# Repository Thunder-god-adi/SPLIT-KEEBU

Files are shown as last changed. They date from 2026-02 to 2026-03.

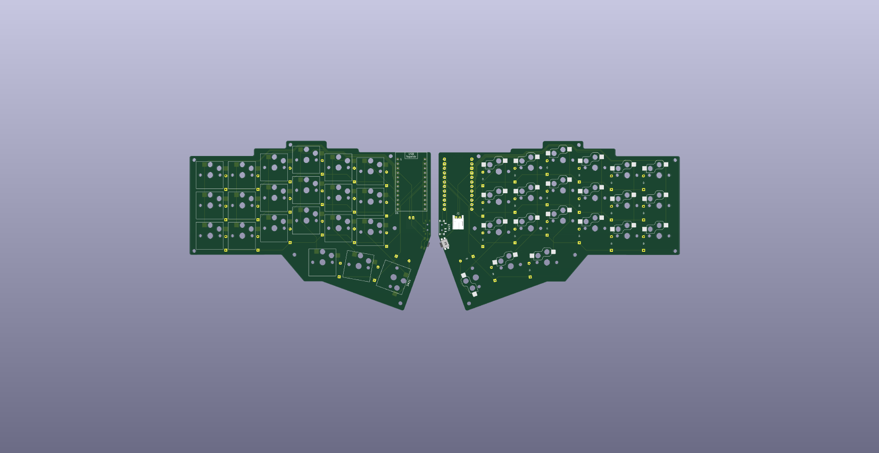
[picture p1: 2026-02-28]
Images/Screenshot 2026-02-26 025907.png

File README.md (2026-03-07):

This my 42 key wireless split keyboard! It follows the corne layout I believe with a 3x6+3 layout. This is my 2nd ever PCB project, so it was very fun! It will use 42 choc switches and hotswap sockets, and is powered by a supermini nrf52840 (nice nano clone).

BOM Request for GRANT:
| Component | Quantity | Price (USD) | Source |
| --- | --- | --- | --- |
|Supermini NRF52840| 2 | $17 | https://robu.in/product/promicro-nrf52840-development-board/
| TTC Low Profile Red Switch | 50 | $19  |https://stackskb.com/store/ttc-low-profile-red-switch-linear/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 |
| PCB | 5 for each side | $32 | JLCPCB |
| Hotswap Sockets | 42 | $7 | https://neomacro.in/products/kailh-mx-hotswap-socket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
| Keycaps | 42 | $20 | https://neomacro.in/products/chocfox-cfx-choc-blank-keycaps?variant=48049351557398




482879733-ef8a3eea-bddf-495d-9658-84fa35c47ed0

**JLC**




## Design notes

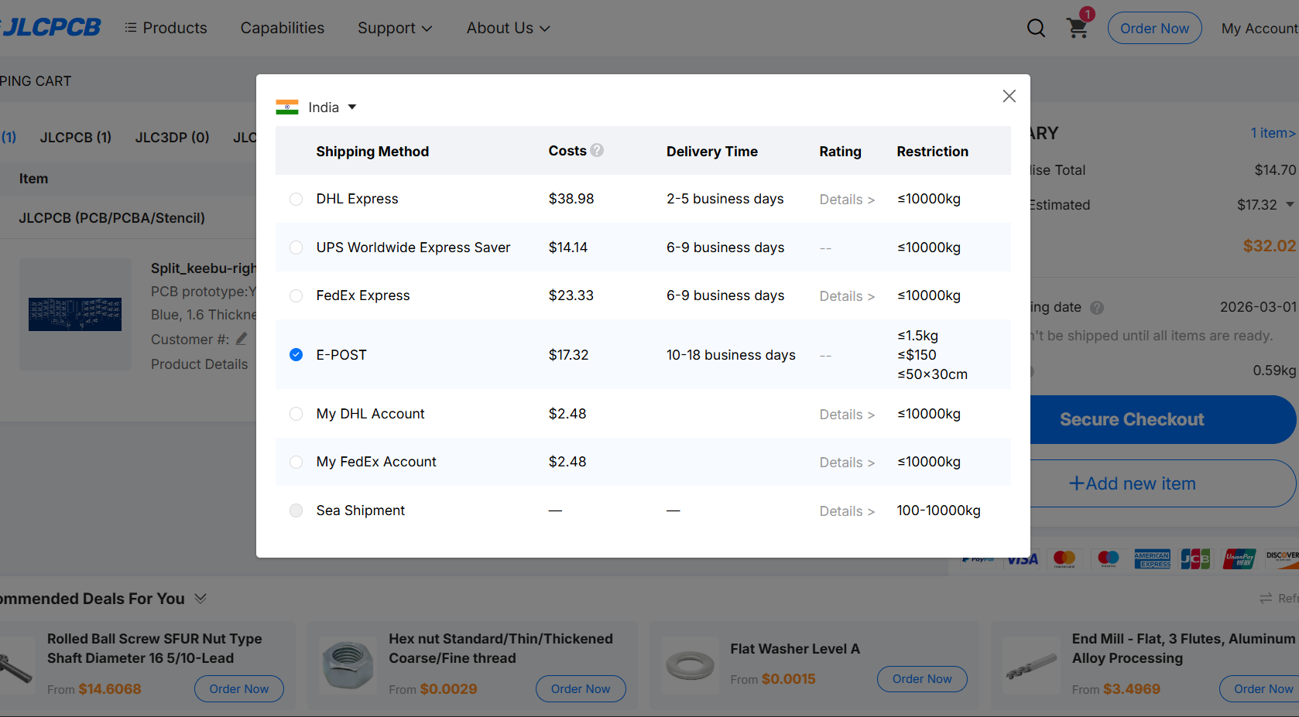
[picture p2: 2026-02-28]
Images/Screenshot 2026-02-26 030301.png

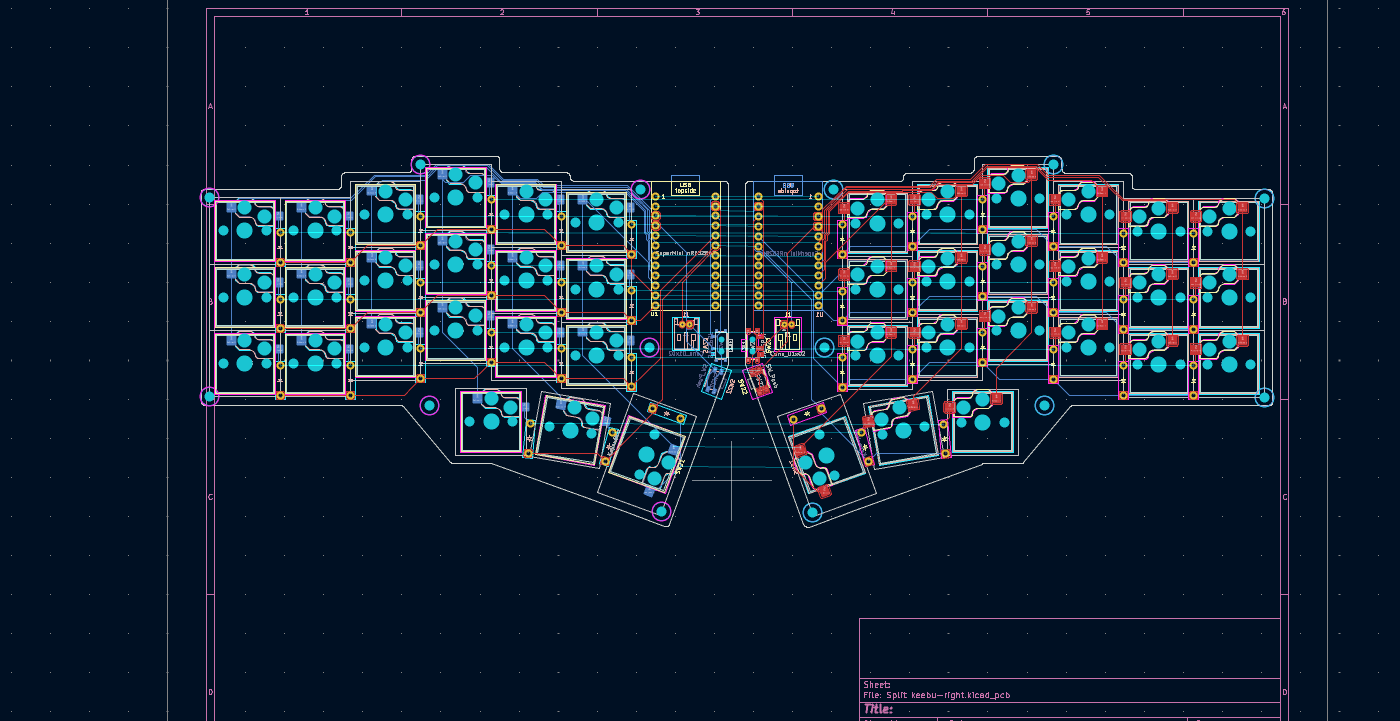
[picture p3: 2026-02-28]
Images/Screenshot 2026-02-26 025851.png

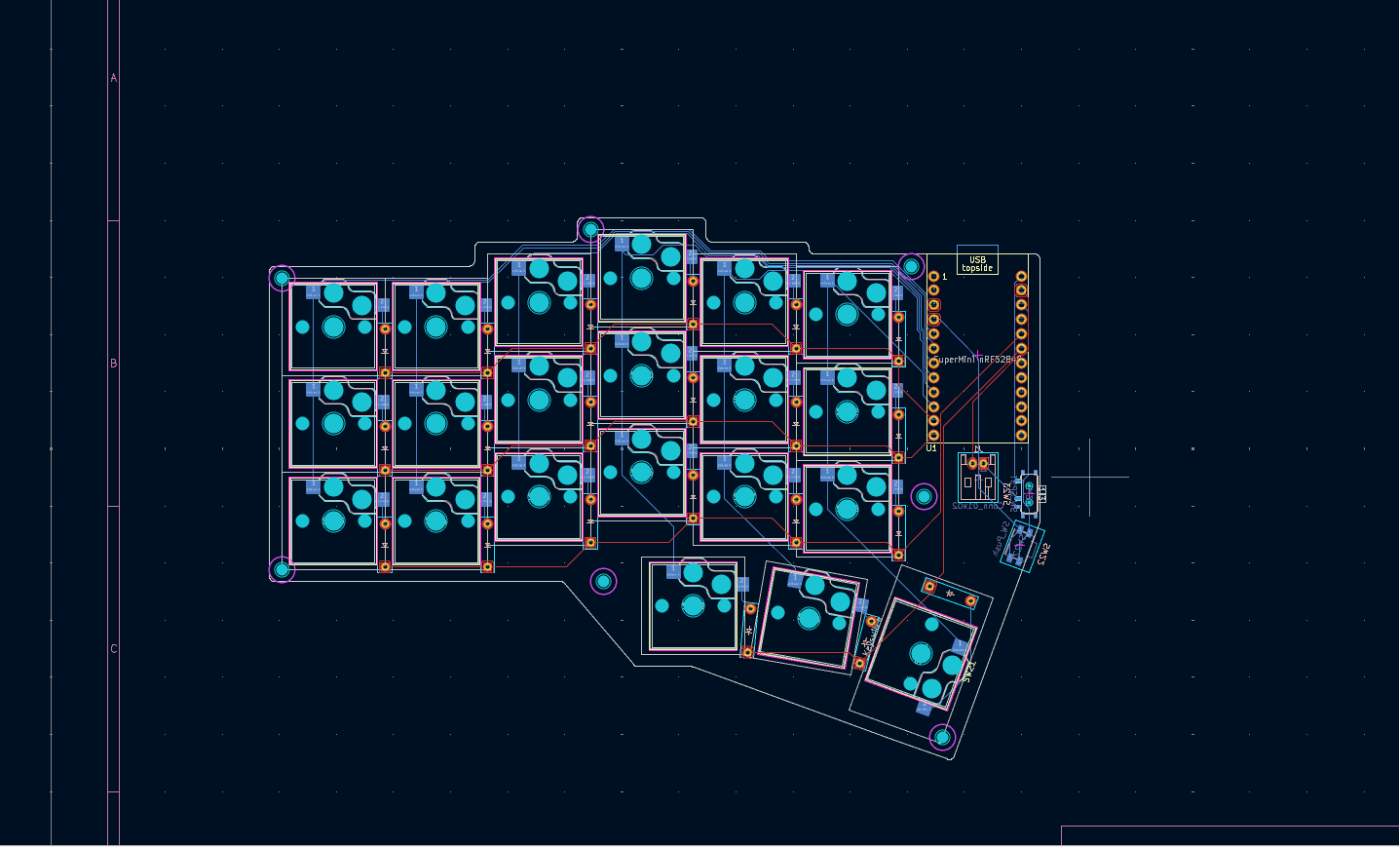
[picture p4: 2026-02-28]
Images/Screenshot 2026-02-26 025321.png

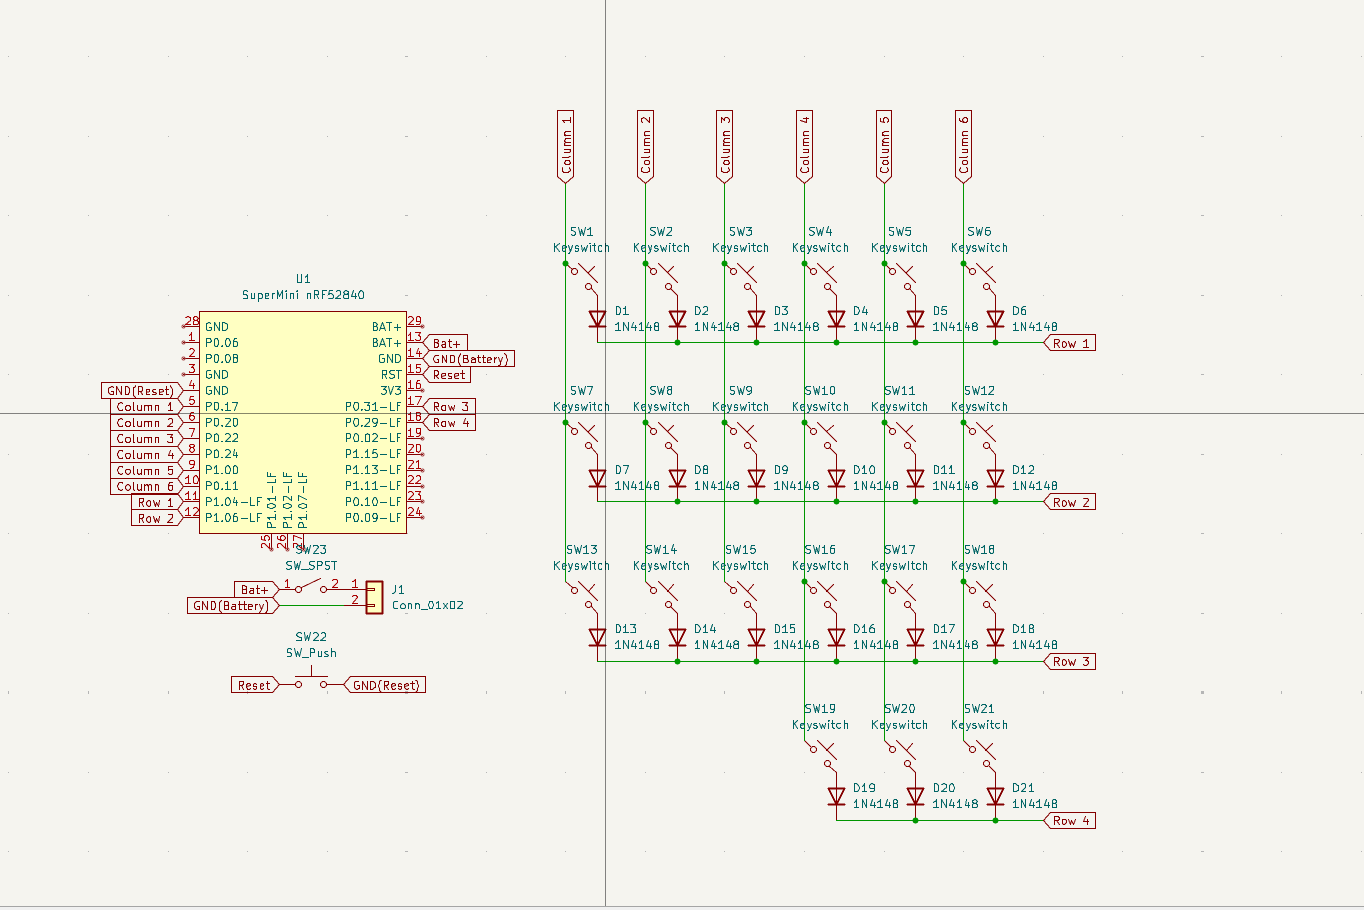
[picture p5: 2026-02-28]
Images/Screenshot 2026-02-26 025339.png

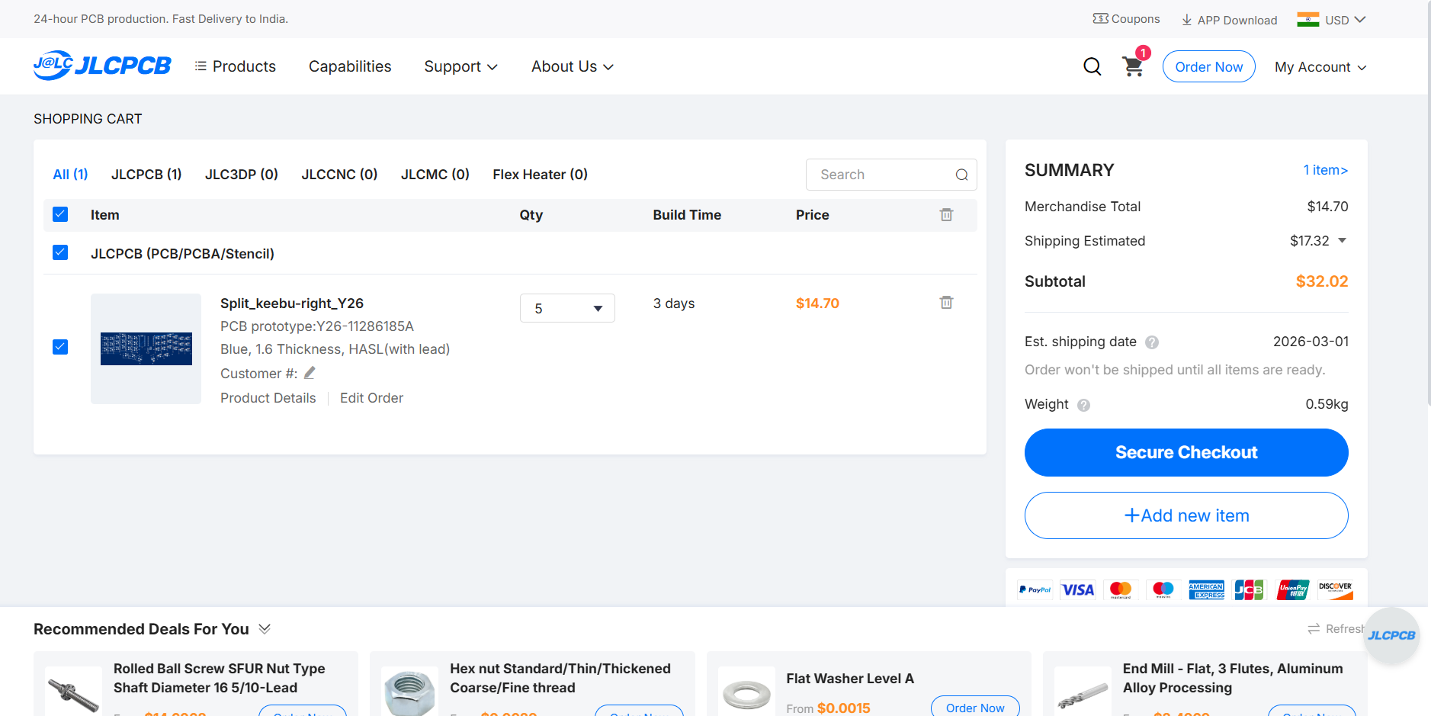
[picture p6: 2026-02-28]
Images/Screenshot 2026-02-26 030311.png

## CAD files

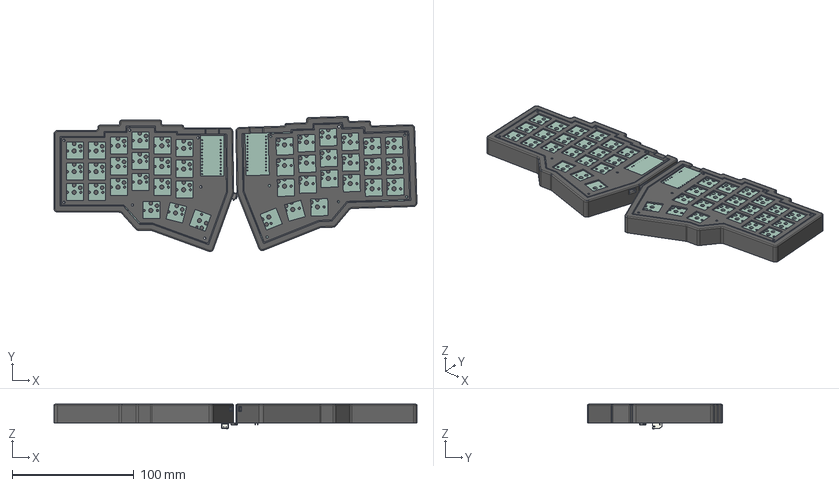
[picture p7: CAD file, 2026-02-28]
CAD/Assembly.step
298.3 x 111.1 x 20.2 mm
root
root001
root002
root003
root004
root005
root006
root007
root008
root009
root010
root011
root012
root013
root014
Panasonic_EVQPUJ_EVQPUA x 2
JST_PH_S2B-PH-K_1x02_P2.00mm_Horizontal x 2
Split keebu-right_PCB_1
Split keebu-right_PCB_2
root017
root018

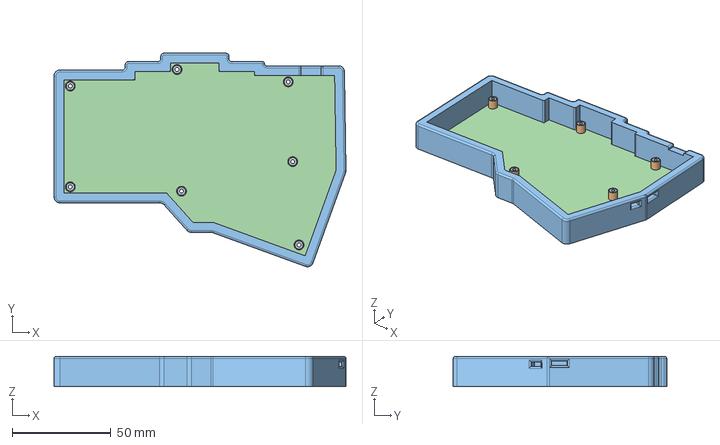
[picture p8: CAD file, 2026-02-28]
CAD/case_left.step
147.7 x 108.1 x 15.3 mm

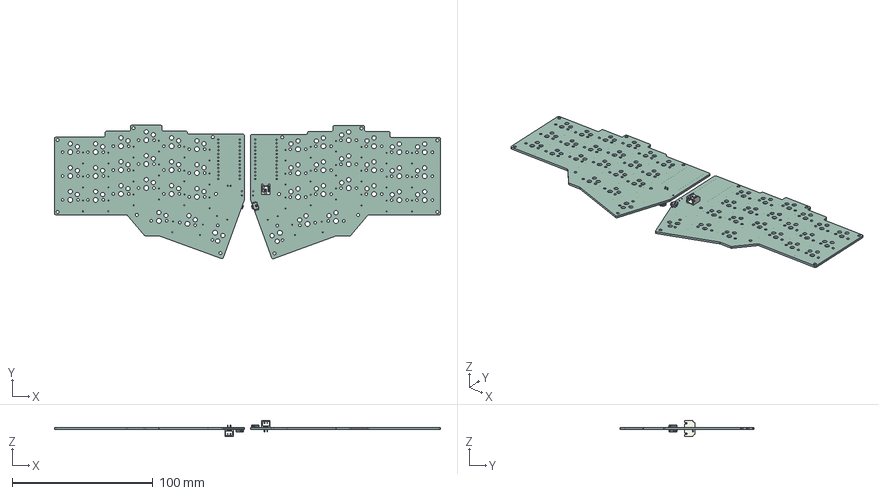
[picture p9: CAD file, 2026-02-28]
PCB/right/hacker-keeb-right.step
274.4 x 95.0 x 11.4 mm
Panasonic_EVQPUJ_EVQPUA x 2
JST_PH_S2B-PH-K_1x02_P2.00mm_Horizontal x 2
Split keebu-right_PCB_1
Split keebu-right_PCB_2

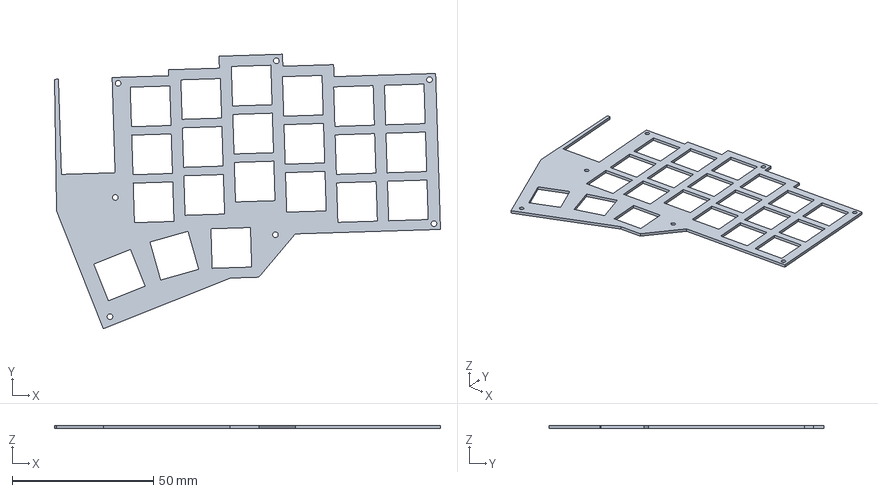
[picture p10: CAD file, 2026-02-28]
CAD/plate_right.step
136.7 x 97.2 x 1.20 mm

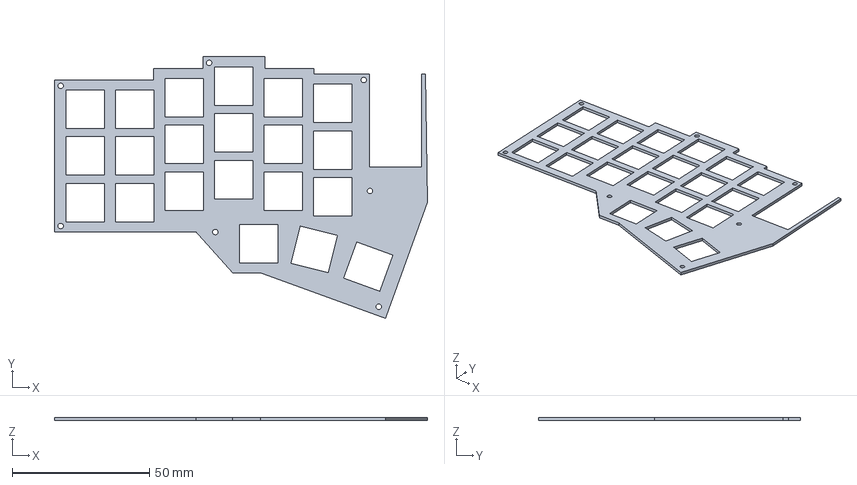
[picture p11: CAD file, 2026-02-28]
CAD/plate_left.step
135.7 x 95.2 x 1.20 mm

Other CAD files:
CAD/case_right.step

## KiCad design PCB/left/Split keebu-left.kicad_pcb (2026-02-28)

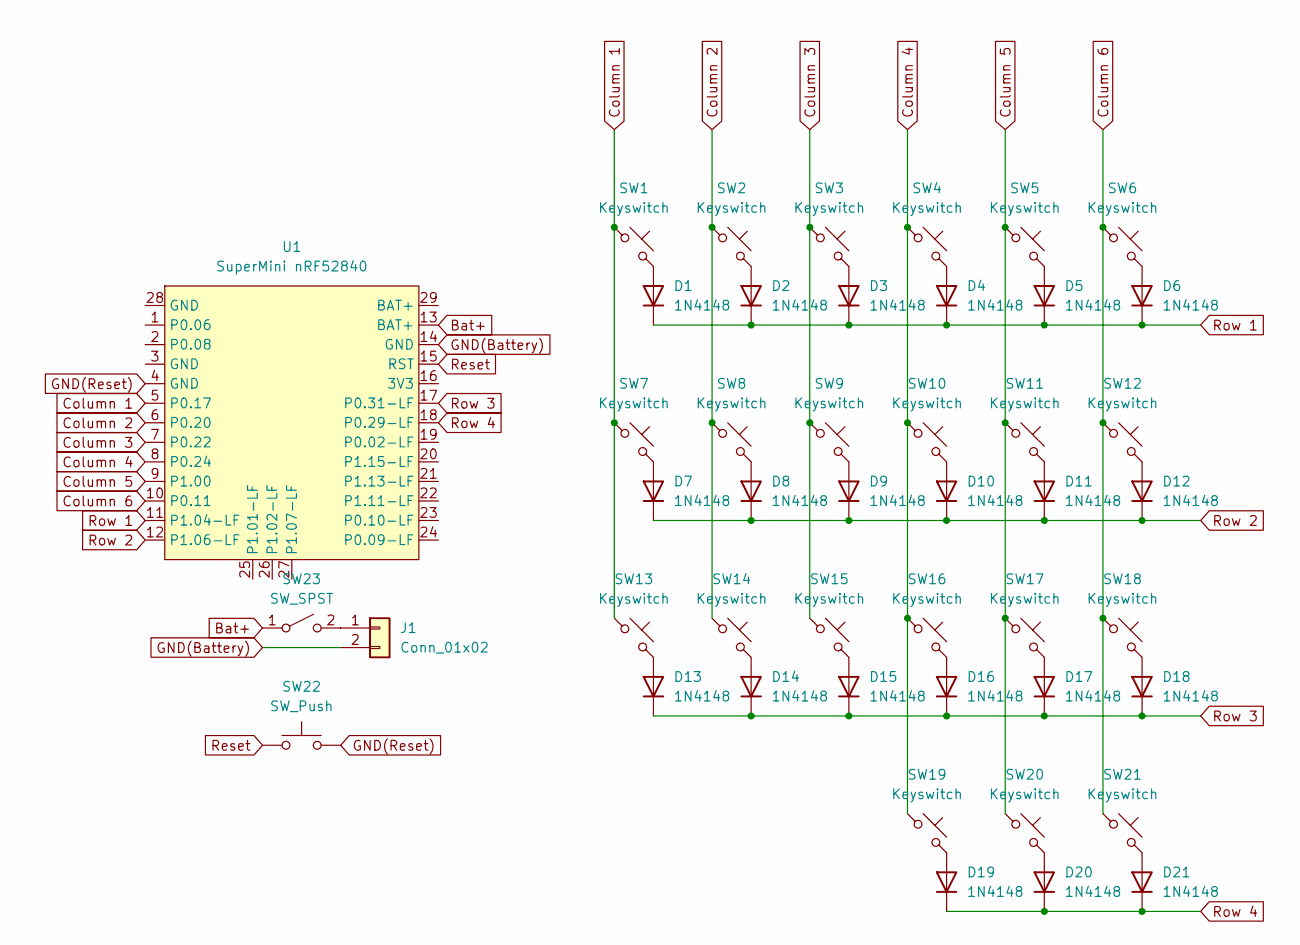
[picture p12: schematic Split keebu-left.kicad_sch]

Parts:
D1, D2, D3, D4, D5, D6, D7, D8, D9, D10, D11, D12, D13, D14, D15, D16, D17, D18, D19, D20, D21: 1N4148; Diode_DO-35
J1: Conn_01x02; JST_PH_S2B-PH-K_1x02_P2.00mm_Horizontal
SW1, SW2, SW3, SW4, SW5, SW6, SW7, SW8, SW9, SW10, SW11, SW12, SW13, SW14, SW15, SW16, SW17, SW18, SW19, SW20: Keyswitch; Hotswap_Choc_V1_1.00u
SW21: Keyswitch; Hotswap_Choc_V1_1.50u
SW22: SW_Push; Panasonic_EVQPUJ_EVQPUA
SW23: SW_SPST; Switch_MSK12C02
U1: SuperMini nRF52840; SuperMini_nRF52840_H_USBup

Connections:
Bat+: SW23.1 (A), U1.13 (BAT+)
Column 1: SW1.1, SW7.1, SW13.1, U1.5 (P0.17)
Column 2: SW2.1, SW8.1, SW14.1, U1.6 (P0.20)
Column 3: SW3.1, SW9.1, SW15.1, U1.7 (P0.22)
Column 4: SW4.1, SW10.1, SW16.1, SW19.1, U1.8 (P0.24)
Column 5: SW5.1, SW11.1, SW17.1, SW20.1, U1.9 (P1.00)
Column 6: SW6.1, SW12.1, SW18.1, SW21.1, U1.10 (P0.11)
GND(Battery): J1.2, U1.14 (GND)
GND(Reset): SW22.2, U1.4 (GND)
unnamed: D1.2 (A), SW1.2
unnamed: D2.2 (A), SW2.2
unnamed: D3.2 (A), SW3.2
unnamed: D4.2 (A), SW4.2
unnamed: D5.2 (A), SW5.2
unnamed: D6.2 (A), SW6.2
unnamed: D7.2 (A), SW7.2
unnamed: D8.2 (A), SW8.2
unnamed: D9.2 (A), SW9.2
unnamed: D10.2 (A), SW10.2
unnamed: D11.2 (A), SW11.2
unnamed: D12.2 (A), SW12.2
unnamed: D13.2 (A), SW13.2
unnamed: D14.2 (A), SW14.2
unnamed: D15.2 (A), SW15.2
unnamed: D16.2 (A), SW16.2
unnamed: D17.2 (A), SW17.2
unnamed: D18.2 (A), SW18.2
unnamed: D19.2 (A), SW19.2
unnamed: D20.2 (A), SW20.2
unnamed: D21.2 (A), SW21.2
unnamed: J1.1, SW23.2 (B)
Reset: SW22.1, U1.15 (RST)
Row 1: D1.1 (K), D2.1 (K), D3.1 (K), D4.1 (K), D5.1 (K), D6.1 (K), U1.11 (P1.04-LF)
Row 2: D7.1 (K), D8.1 (K), D9.1 (K), D10.1 (K), D11.1 (K), D12.1 (K), U1.12 (P1.06-LF)
Row 3: D13.1 (K), D14.1 (K), D15.1 (K), D16.1 (K), D17.1 (K), D18.1 (K), U1.17 (P0.31-LF)
Row 4: D19.1 (K), D20.1 (K), D21.1 (K), U1.18 (P0.29-LF)

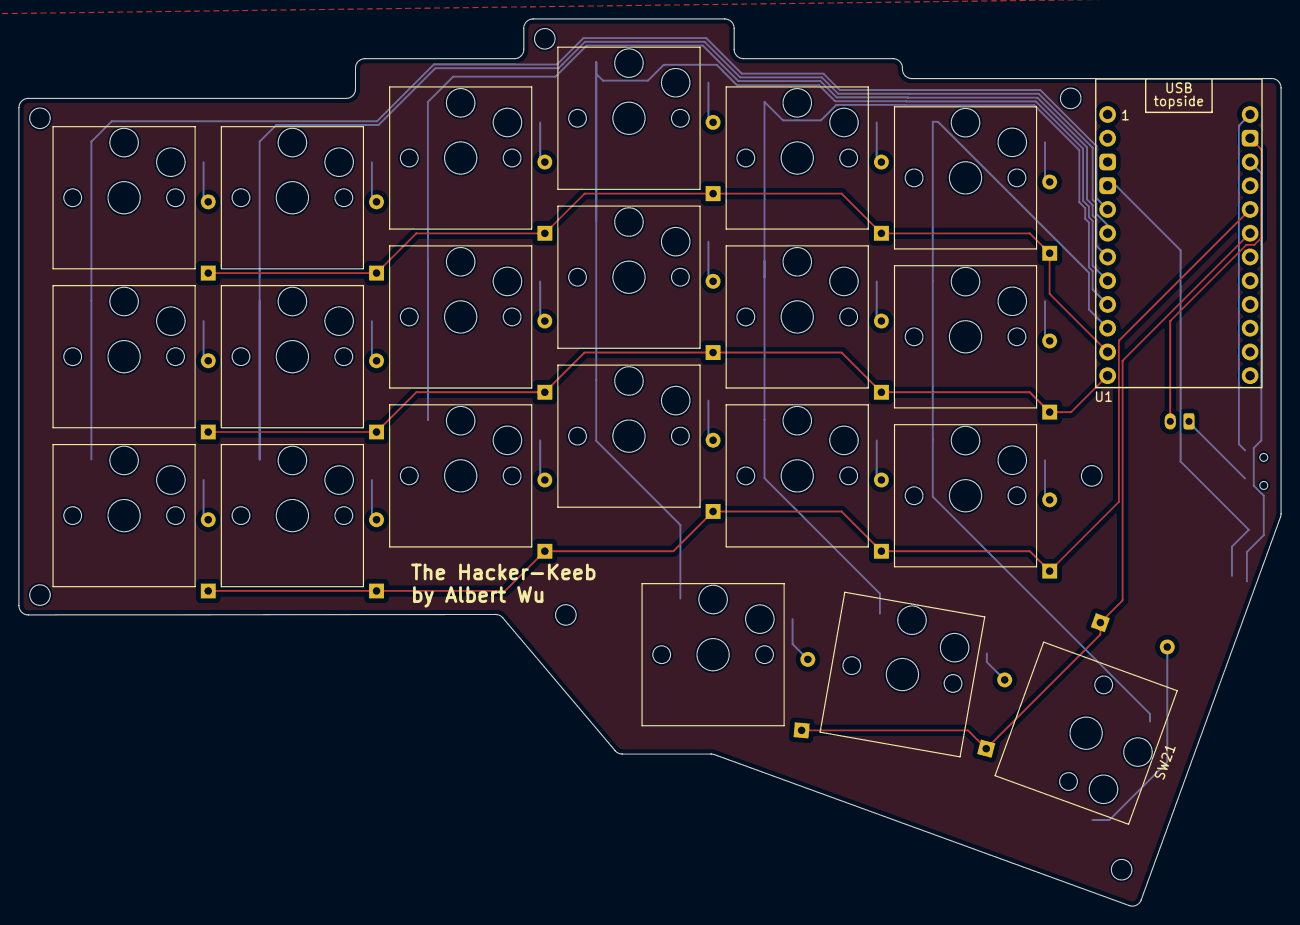
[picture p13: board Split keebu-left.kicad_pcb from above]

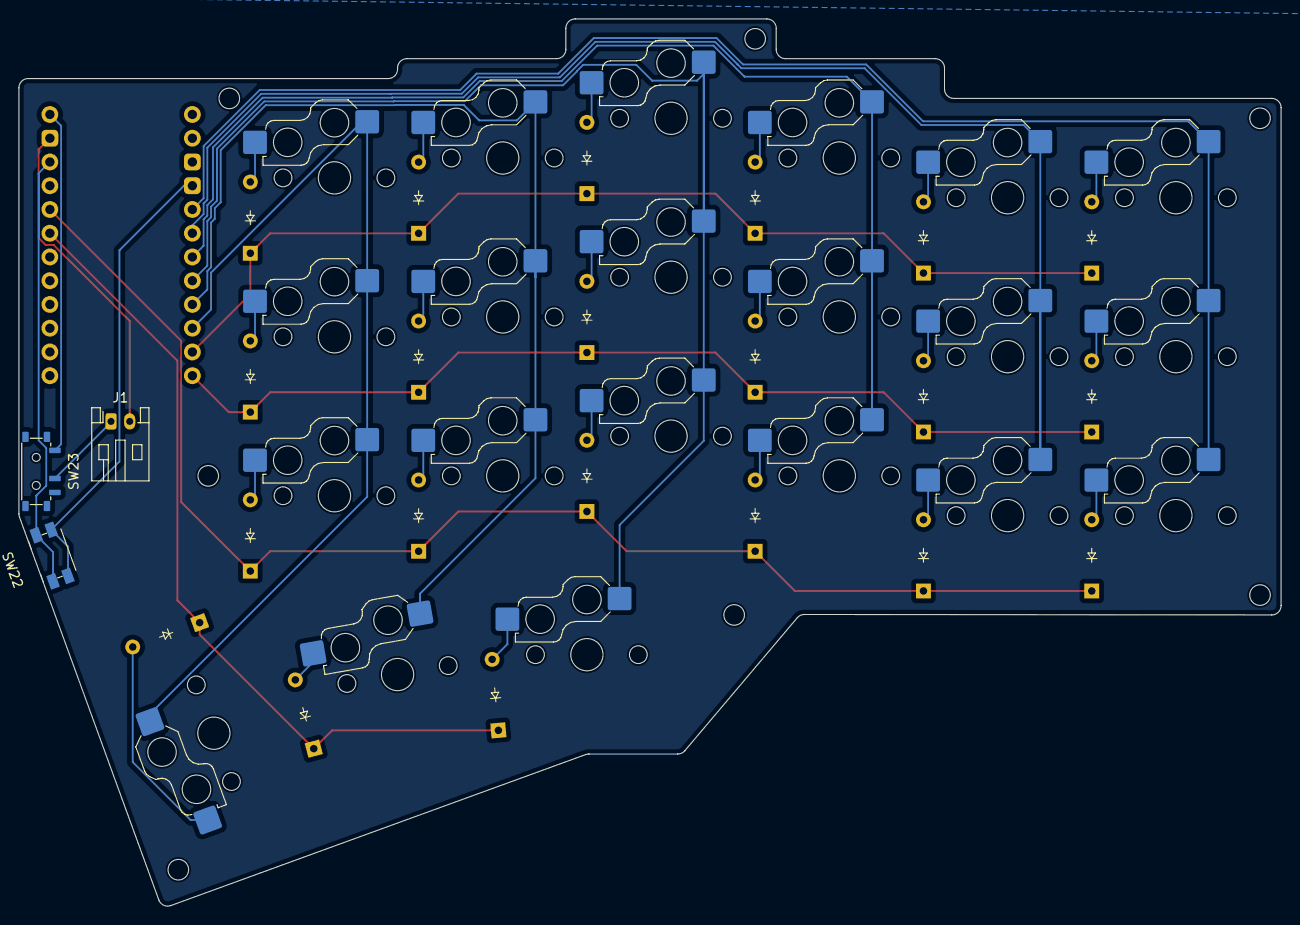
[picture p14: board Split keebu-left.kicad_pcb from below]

Board: 2 copper layers, 135.0 x 94.9 mm, 46 parts (24 on the bottom side), 36 nets.
